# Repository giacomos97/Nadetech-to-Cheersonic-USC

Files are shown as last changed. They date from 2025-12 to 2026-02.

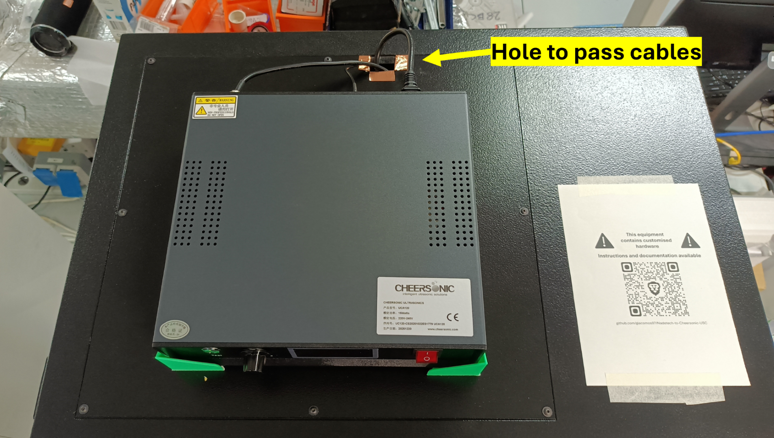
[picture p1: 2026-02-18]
resources/Cheersonic_generator_installed.png

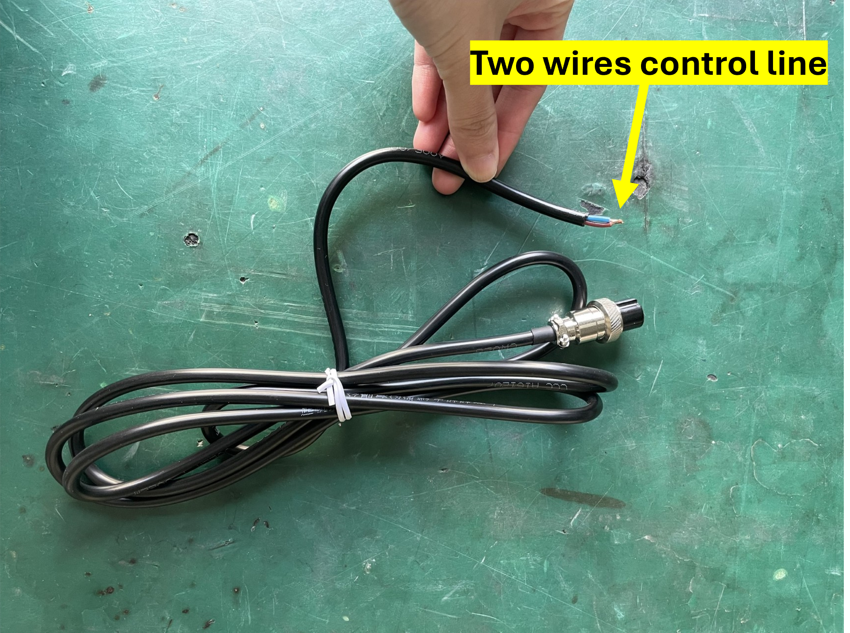
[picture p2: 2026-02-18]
resources/Cheersonic_control_line.png

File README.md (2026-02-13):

# Nadetech-to-Cheersonic-USC

Hardware and software needed to upgrade a Nadetech Ultrasonic Spray Coater with Cheersonic components.

Please refer to [this project's Wiki](https://github.com/giacomos97/Nadetech-to-Cheersonic-USC/wiki) for all the technical details and instructions.

## Description

Nadetech no longer offers support for their ultrasonic spray coating equipment. If you have experienced failure of the ultrasonic nozzle components, you may consider replacing them with components from another manufacturer. This project aims to upgrade the ultrasonic generator and nozzle of a Nadetech Ultrasonic Spray Coater with Cheersonic components.

The primary objective is to replace the existing ultrasonic spray system with the Cheersonic Ultrasonic Spray System UCA120. The key challenge is ensuring compatibility between the new Cheersonic system and the existing Nadetech equipment. This requires an ad-hoc interface because the current PiezoDrive generator is controlled via an RS485 interface, while the Cheersonic equipment employs a 2-wire control line.

The Nadetech electronics continuously communicates via the RS485 interface with the PiezoDrive ultrasonic generator. If this communication fails, the equipment will not perform the ultrasonic deposition. Therefore, an intermediary solution (like an Arduino) is required to manage on/off commands.

This project provides guidance and detailed instructions for installation and usage. The project involves replacing the existing PiezoDrive controller and nozzle with the Cheersonic system and includes detailed instructions for hardware and software upgrades, a list of components required for the upgrade, and installation and setup guides.

## Contributing

We welcome any contributions, improvements, or bug reports to this project. Your input is valuable and helps improve the project for everyone.

## Disclaimer

Please note the following:

- This project is not affiliated with Cheersonic or Nadetech.
- Be aware of the potential consequences of this upgrade operation, as you may irreparably damage your equipment.
- Perform any action at your own risk. Neither Cheersonic nor Nadetech is available to provide technical assistance for this project.

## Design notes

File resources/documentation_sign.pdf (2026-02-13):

Instructions and documentation available

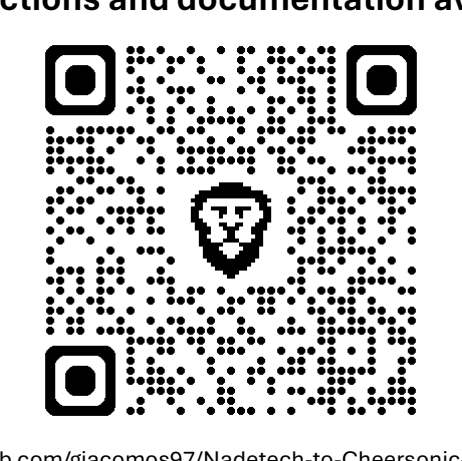
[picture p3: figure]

github.com/giacomos97/Nadetech-to-Cheersonic-USC

This equipment
contains customised
hardware
Instructions and documentation available

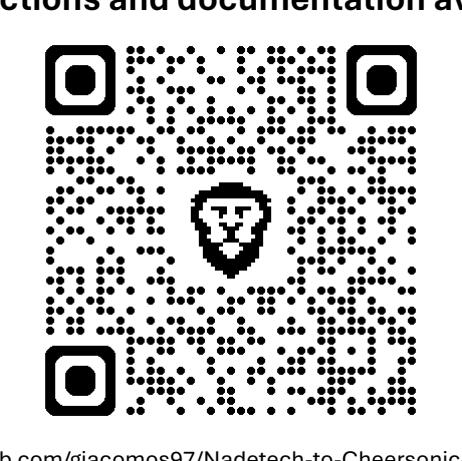
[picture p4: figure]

github.com/giacomos97/Nadetech-to-Cheersonic-USC

This equipment
contains customised
hardware

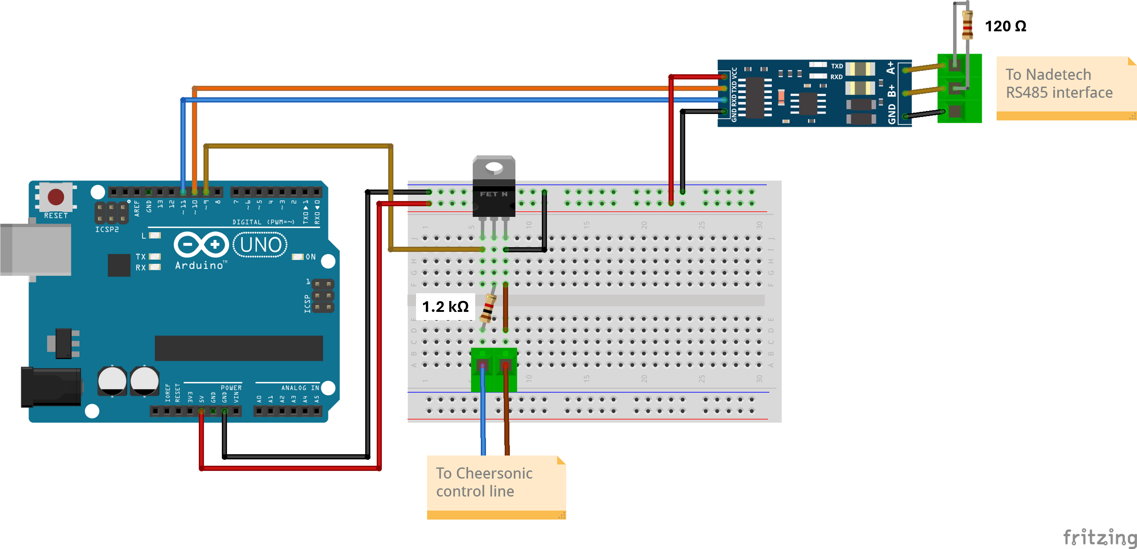
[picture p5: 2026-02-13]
resources/schematic.png

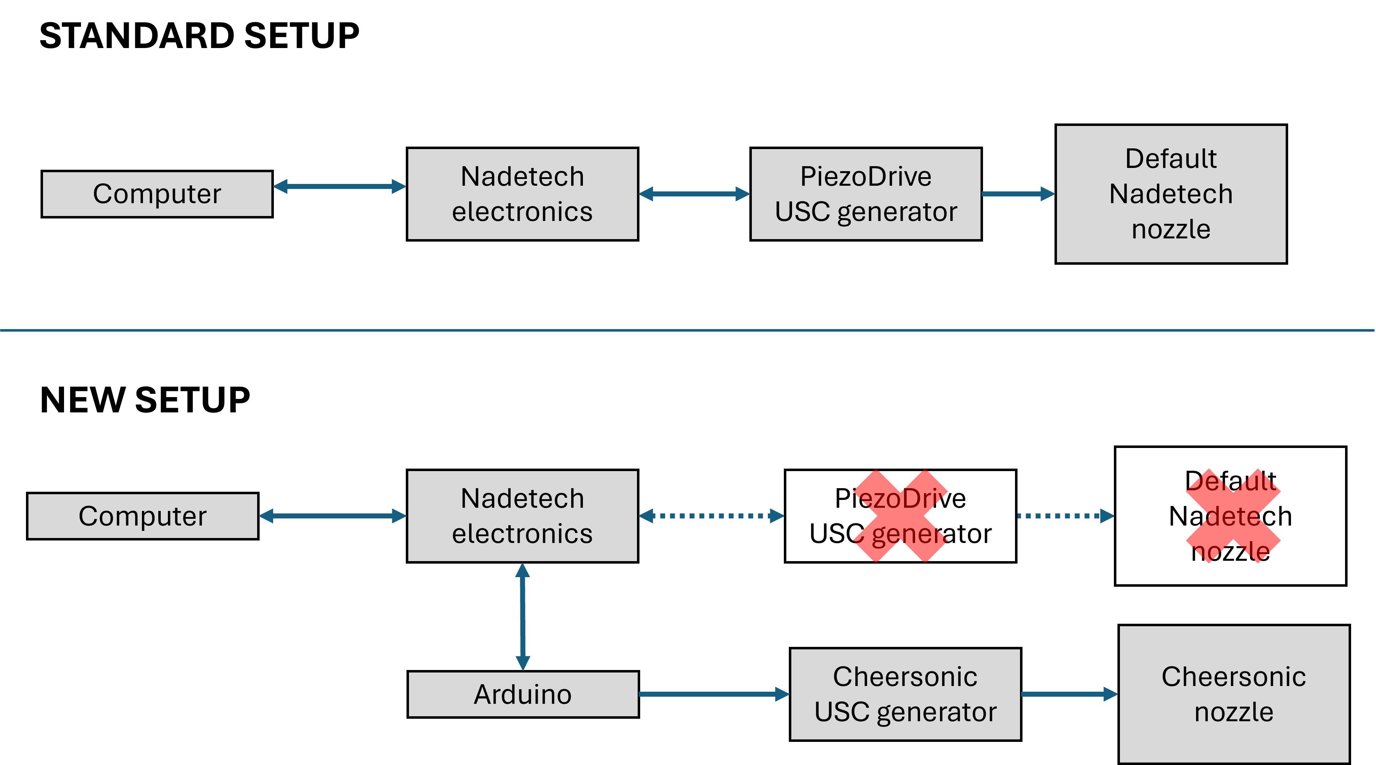
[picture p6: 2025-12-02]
resources/upgrade_overview.png

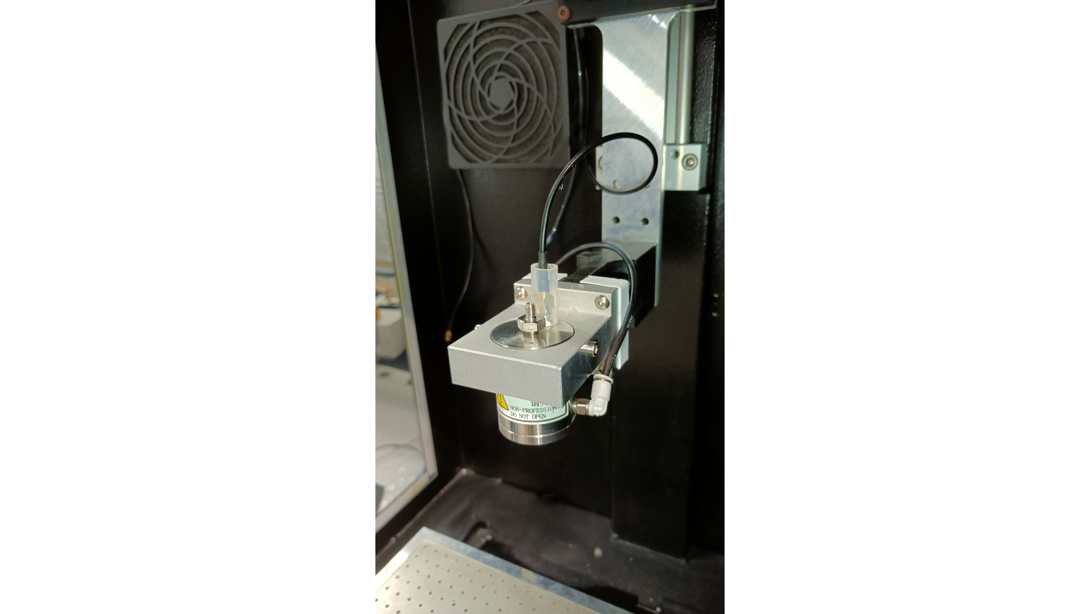
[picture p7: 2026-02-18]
resources/Cheersonic_nozzle_detail.png

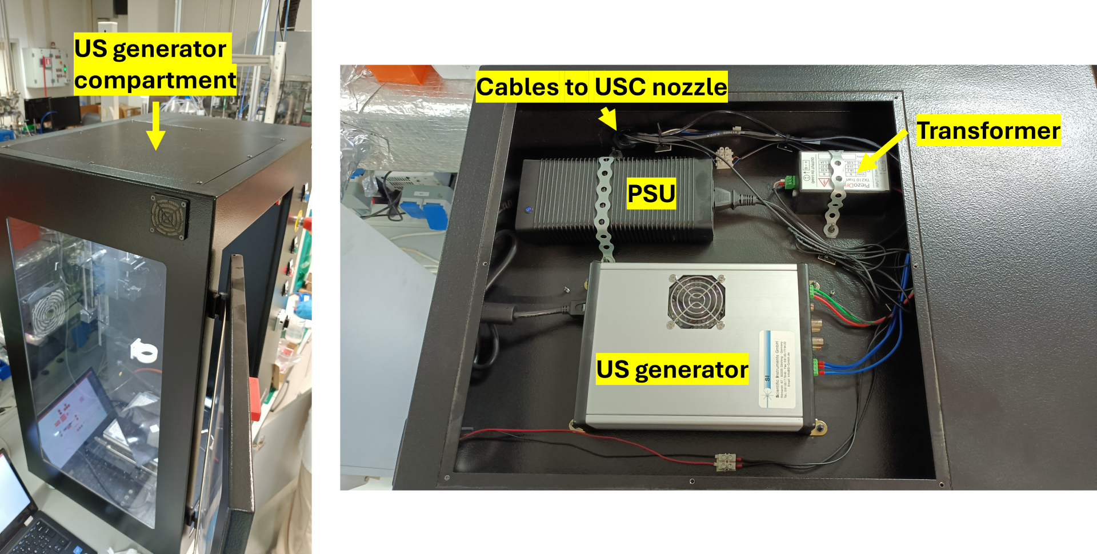
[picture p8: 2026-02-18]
resources/US_generator_compartment.png

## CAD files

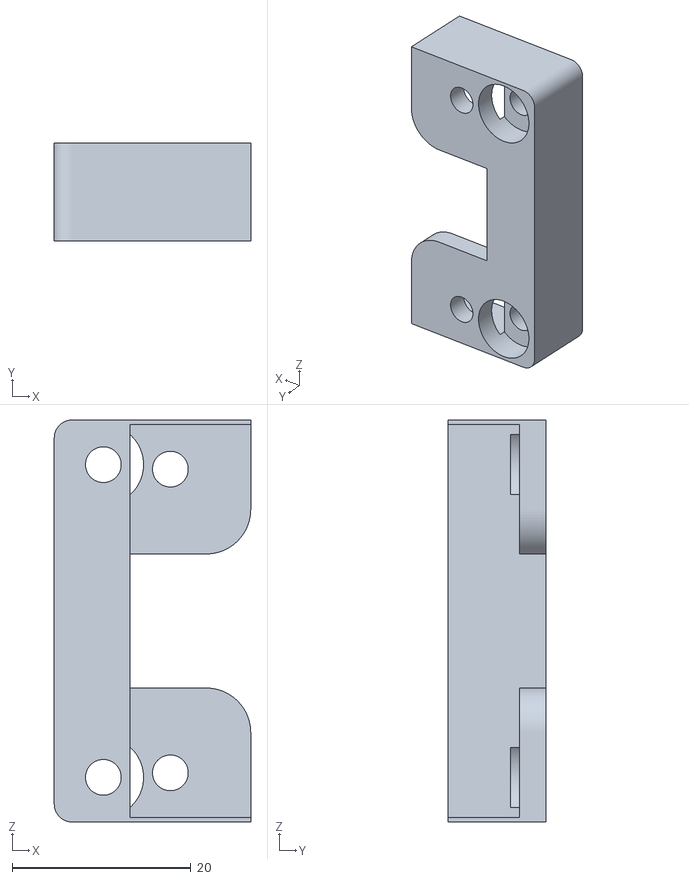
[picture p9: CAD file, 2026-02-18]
resources/US_head_adapter_left.stl
22.0 x 11.0 x 45.0

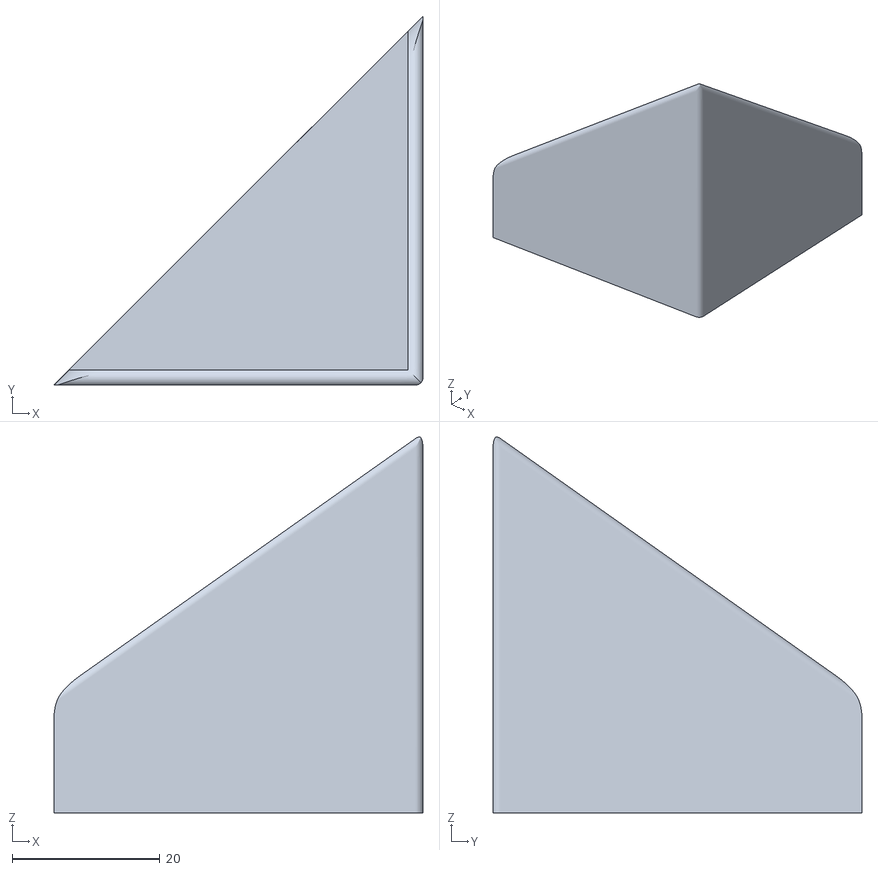
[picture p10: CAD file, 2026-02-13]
resources/corner_bracket.stl
50.0 x 50.0 x 50.9

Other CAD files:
resources/US_head_adapter_right.stl

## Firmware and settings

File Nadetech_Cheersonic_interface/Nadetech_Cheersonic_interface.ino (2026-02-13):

#include <SoftwareSerial.h>

// Arduino board pin assignement
SoftwareSerial Slave(11, 10);

// MOSFET pin assignement
const int mosfetPin = 9;

// Variable and buffer to collect incoming RS485 commands
char val;
char inputBuffer[20];           

// Variables to trigger responses when RS485 command received
int inputIndex = 0;
bool commandReceived = false;

// Track current ON/OFF state of the USC generator
bool generatorEnabled = false;

// Dummy responses to getSTATE request. 
/* Refer to https://github.com/PiezoDrive/RS485-API/blob/master/README.md#get-amplifier-state */

char dummyResponseDisabled[80] = {
  0, 0, 0, 0, 0, 0, 0, 0, // (enabled, phase tracking, etc.)
  0x00, 0x00, 0xC8, 0x42, // 230.0 (voltage)
  0x00, 0x00, 0x00, 0x42, // 50.0 (frequency)
  0x00, 0x00, 0x00, 0x42, // 50.0 (min frequency)
  0x00, 0x00, 0x00, 0x42, // 50.0 (max frequency)
  0x00, 0x00, 0x00, 0x00, // 0.0 (target phase)
  0x00, 0x00, 0x00, 0x00, // 0.0 (phase control gain)
  0x00, 0x00, 0x00, 0x00, // 0.0 (target current)
  0x00, 0x00, 0x00, 0x00, // 0.0 (current control gain)
  0x00, 0x00, 0x00, 0x00, // 0.0 (target power)
  0x00, 0x00, 0x00, 0x00, // 0.0 (power control gain)
  0x00, 0x00, 0x00, 0x00, // 0.0 (max load power)
  0x00, 0x00, 0x00, 0x00, // 0.0 (amplifier power)
  0x00, 0x00, 0x00, 0x00, // 0.0 (load power)
  0x00, 0x00, 0x00, 0x00, // 0.0 (temperature)
  0x00, 0x00, 0x00, 0x00, // 0.0 (measured phase)
  0x00, 0x00, 0x00, 0x00, // 0.0 (measured current)
  0x00, 0x00, 0x00, 0x00  // 0.0 (impedance)
};

char dummyResponseEnabled[80] = {
  1, 0, 0, 0, 0, 0, 0, 0, // (enabled, phase tracking, etc.)
  0x00, 0x00, 0xC8, 0x42, // 230.0 (voltage)
  0x00, 0x00, 0x00, 0x42, // 50.0 (frequency)
  0x00, 0x00, 0x00, 0x42, // 50.0 (min frequency)
  0x00, 0x00, 0x00, 0x42, // 50.0 (max frequency)
  0x00, 0x00, 0x00, 0x00, // 0.0 (target phase)
  0x00, 0x00, 0x00, 0x00, // 0.0 (phase control gain)
  0x00, 0x00, 0x00, 0x00, // 0.0 (target current)
  0x00, 0x00, 0x00, 0x00, // 0.0 (current control gain)
  0x00, 0x00, 0x00, 0x00, // 0.0 (target power)
  0x00, 0x00, 0x00, 0x00, // 0.0 (power control gain)
  0x00, 0x00, 0x00, 0x00, // 0.0 (max load power)
  0x00, 0x00, 0x00, 0x00, // 0.0 (amplifier power)
  0x00, 0x00, 0x00, 0x00, // 0.0 (load power)
  0x00, 0x00, 0x00, 0x00, // 0.0 (temperature)
  0x00, 0x00, 0x00, 0x00, // 0.0 (measured phase)
  0x00, 0x00, 0x00, 0x00, // 0.0 (measured current)
  0x00, 0x00, 0x00, 0x00  // 0.0 (impedance)
};

void setup() {
  
  // Initialize the MOSFET control pin
  pinMode(mosfetPin, OUTPUT);

  // Start with the Cheersonic generator off
  digitalWrite(mosfetPin, LOW);

  //Computer-Arduino interface
  //Serial.begin(9600);
  
  //Arduino-Nadetech interface
  Slave.begin(9600);

}

void loop() {
  
  // Forward data from Serial input to Slave
  while (Serial.available()) {
    val = Serial.read();
    Slave.write(val);
  }

  // Collect data from Slave into inputBuffer
  while (Slave.available()) {
    val = Slave.read();

    if (val == '\r') {
      // Command received
      inputBuffer[inputIndex] = '\0';   // Null-terminate the string
      commandReceived = true;           // Trigger response via RS485
      inputIndex = 0;                   // Reset input index counter
    } else {
      // Command not received, contine recording in buffer
      inputBuffer[inputIndex++] = val;
    }
  }

  // Respond via RS485 if command received
  if (commandReceived) {
    delay(3); // "Allow 2.5 ms between commands"

    if (strcmp(inputBuffer, "getSTATE") == 0) {
      // Respond to getSTATE request

      if (generatorEnabled){
        // Send dummy 80-byte enabled response
        Slave.write(dummyResponseEnabled, 80);
        Serial.println("Working enabled\r");
      }else{
        // Send dummy 80-byte disabled response
        Slave.write(dummyResponseDisabled, 80);
        Serial.println("Working disabled\r");
      }

    } else if (strcmp(inputBuffer, "ENABLE") == 0) {

      if (!generatorEnabled){
        // Enable Cheersonic generator
        digitalWrite(mosfetPin, HIGH);
      }
      // Respond to ENABLE request
      generatorEnabled = true;  // Keep track of new state
      Slave.write("TRUE\r");
      Serial.println("Enabled\r");
      
    } else if (strcmp(inputBuffer, "DISABLE") == 0) {

      if (generatorEnabled){
        // Disable Cheersonic generator
        digitalWrite(mosfetPin, LOW);
      }

      // Respond to DISABLE request
      generatorEnabled = false; // Keep track of new state
      Slave.write("TRUE\r");
      Serial.println("Disabled\r");    
    }

    commandReceived = false;  // Reset response trigger
  }
}

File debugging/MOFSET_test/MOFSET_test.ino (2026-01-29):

# Define MOFSET control pin
const int mosfetPin = 9;

void setup() {

  # Configure digital pin
  pinMode(mosfetPin, OUTPUT);
  digitalWrite(mosfetPin, LOW);

  # Start serial communication
  Serial.begin(9600);
  Serial.println("Commands:  1 = ON, 0 = OFF. Type your command:");
}

void loop() {

  if (Serial.available() > 0) {
    # Read user command from terminal
    char received = Serial.read();

    if (received == '1') {
      digitalWrite(mosfetPin, HIGH);
      Serial.println("Status = ON");
    }
    else if (received == '0') {
      digitalWrite(mosfetPin, LOW);
      Serial.println("Status = OFF");
    }
    else{
      Serial.println("Invalid command.");
    }
  }
}

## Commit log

2025-11-27 Initial arduino firmware
    This firmware version allows the Nadetech USC to correctly operate once the original PiezoDrive controller is removed and replaced by the Arduino board.
    [Nadetech_Cheersonic_interface.ino]
2025-12-01 Added on/off control of MOSFET
2025-12-12 Fixed electronic circuit scheme
2026-01-29 Added Arduino code for MOFSET testing
2026-02-13 Added resources for wiki
    [corner_bracket.stl]
2026-02-13 Disabled Arduino-PC serial interface by default
2026-02-18 Added assets
    [US head adapter_left.stl, US head adapter_right.stl]
2026-02-18 Updated assets
    [US_head_adapter_left.stl, US_head_adapter_right.stl]
